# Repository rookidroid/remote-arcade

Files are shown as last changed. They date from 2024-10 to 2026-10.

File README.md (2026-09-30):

# Arcade Remote

A retro-style arcade controller for robots — a 4-way arcade joystick, five arcade buttons and an ESP32-C6, in a 3D-printed cabinet that fits in your hands.






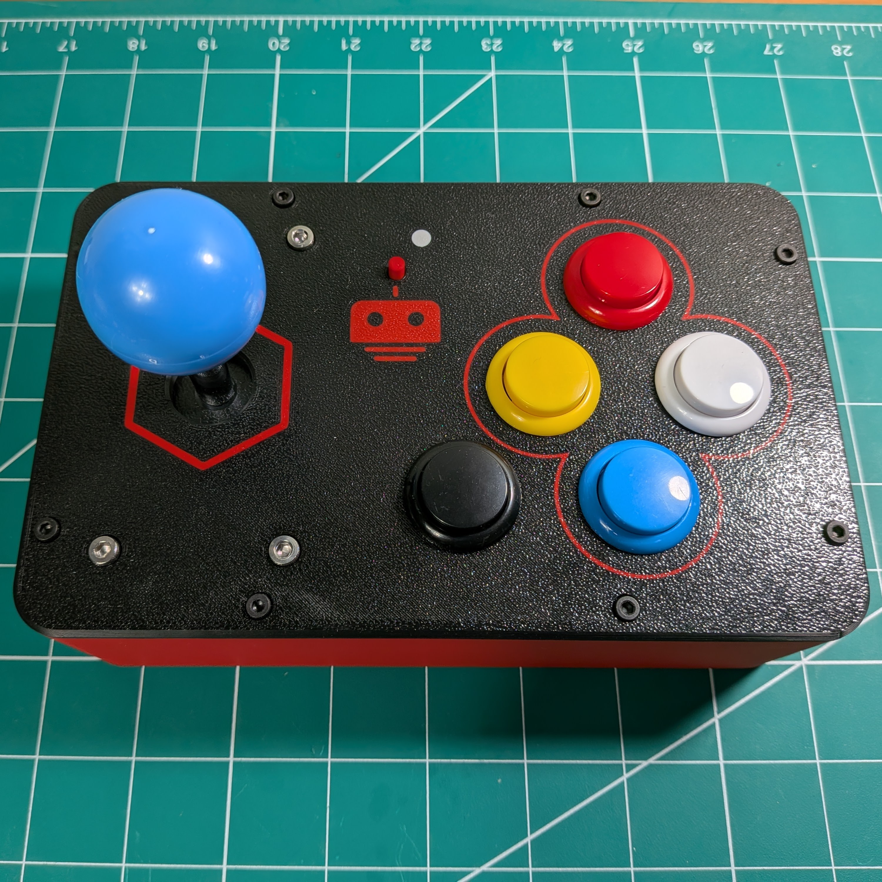
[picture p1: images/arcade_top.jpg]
arcade_top
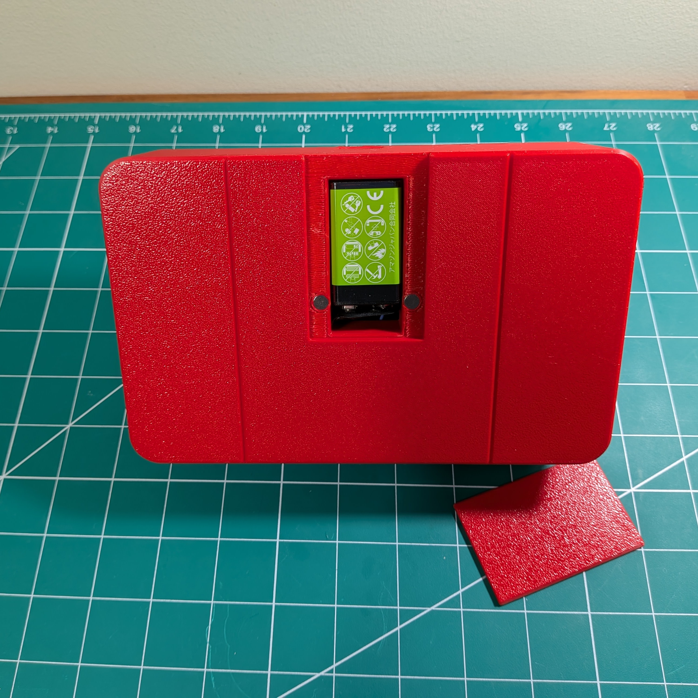
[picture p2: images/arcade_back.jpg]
arcade_back
 

**Jump to:** [Bill of Materials](#bill-of-materials) · [3D-Printed Parts](#3d-printed-parts) · [Assembly](#assembly) · [Firmware](#firmware) · [Controls](#controls) · [UDP Protocol](#udp-protocol) · [Troubleshooting](#troubleshooting)

<details>
<summary><b>Table of Contents</b></summary>

- [Introduction](#introduction)
  - [Specifications](#specifications)
- [Bill of Materials](#bill-of-materials)
  - [Electronics](#electronics)
  - [Connection Diagram](#connection-diagram)
  - [Pin Map](#pin-map)
  - [Other Parts](#other-parts)
- [3D-Printed Parts](#3d-printed-parts)
- [Assembly](#assembly)
- [Firmware](#firmware)
  - [Prerequisites](#prerequisites)
  - [Upload](#upload)
  - [Configuration](#configuration)
  - [Status LED](#status-led)
- [Controls](#controls)
- [UDP Protocol](#udp-protocol)
- [Troubleshooting](#troubleshooting)
- [Related Projects](#related-projects)
- [License](#license)
- [Support](#support)

</details>

## Introduction

This remote turns real arcade hardware into a WiFi controller for the [RookiDroid hexapod](https://github.com/rookidroid/hexapod) — **all three of them**, Nougat, Mochi and Macaroon — and any other robot that speaks the same binary UDP protocol. Only the `ssid` line in the sketch changes between robots; see [Configuration](#configuration).

Prefer a step-by-step walkthrough with photos? The same build is documented as the [Build the Arcade Remote](https://rookidroid.com/build-the-arcade-remote/) guide on rookidroid.com.

- **Real arcade feel** — a microswitch joystick and five snap-in arcade buttons, no analog sticks and no deadzone
- **All-digital inputs** — nine switches on `INPUT_PULLUP` GPIOs, scanned every 5 ms; a command must hold for 30 ms before it is sent, which filters switch bounce and half-pressed button combos
- **WiFi direct to the robot** — the remote joins the robot's own access point, so no router is involved, with WiFi power saving off for low latency
- **Instant send + 20 Hz heartbeat** — a new command goes out as soon as it settles, and the current one is repeated every 50 ms, so releasing a control stops the robot right away
- **Adjustable speed** — five speed levels from 20 % to 100 % of the robot's gait speed, stepped with special + joystick and remembered across power cycles
- **RGB status LED** — shows the link state, what the remote is sending and the speed level, visible through the window in the top panel
- **Battery powered** — a single 9 V battery in a magnetically-latched bay in the back
- **Fully 3D-printed cabinet** — one Bambu Studio project prints the whole enclosure

### Specifications

| Item | Value |
| ---- | ----- |
| **Controller** | ESP32-C6 SuperMini on the RookiDroid remote carrier board |
| **Inputs** | 4-way microswitch joystick + 5 arcade push buttons |
| **Feedback** | 1 × WS2812 (NeoPixel) RGB status LED on `GP8` |
| **Power** | 9 V battery → on-board Mini360 buck converter → 5 V, with a slide switch on the board |
| **Connectivity** | 2.4 GHz WiFi — the remote joins the robot's access point as a station |
| **Control** | 7-byte binary UDP packets to `192.168.4.1:1234`, carrying the command and the speed level |
| **Update rate** | Sent on change (30 ms settle), plus a 20 Hz heartbeat that runs continuously, including standby |
| **Enclosure** | 3D-printed body, cover, bottom plate and magnetic battery cover |

## Bill of Materials

### Electronics

| Name | Thumbnail | Required # | Specifications | Note |
| ---- | --- | --- | --- | ---- |
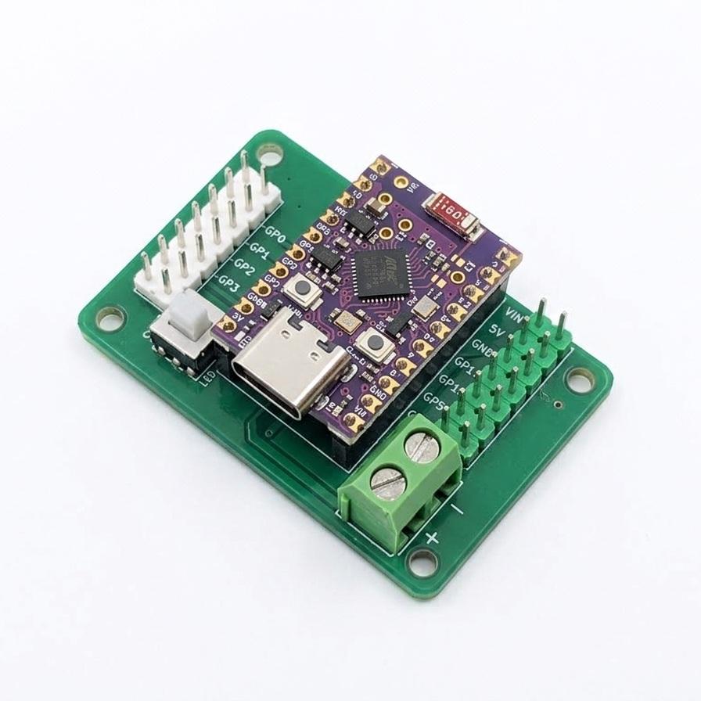
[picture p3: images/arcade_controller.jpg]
controller_board
| Controller board |  | 1 | ESP32-C6 SuperMini on a carrier board with a Mini360 buck converter, power switch, 2-pin battery terminal, a 5-pin joystick header (`GP0`–`GP3`) and a 2×7 button header | [Purchase](https://rookidroid.com/product/arcade-controller-board/) — or use a bare ESP32-C6 SuperMini, wiring the switches straight to the GPIOs in the [pin map](#pin-map) and feeding it 5 V |
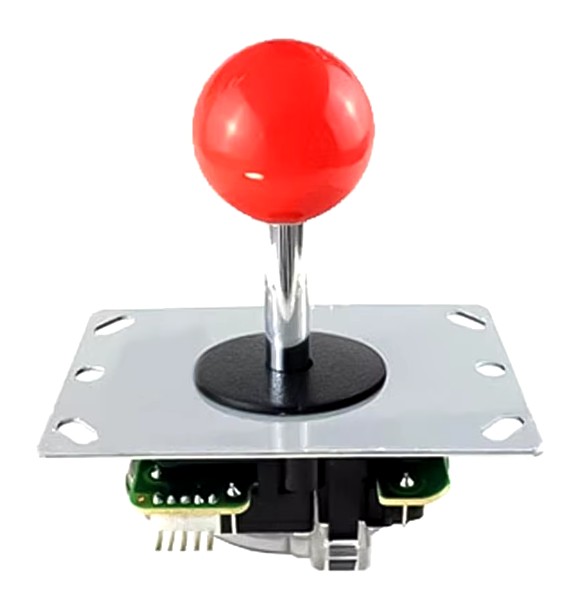
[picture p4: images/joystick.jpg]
joystick
| Arcade joystick |  | 1 | Microswitch joystick, 97 × 65 mm mounting plate, ~119 mm overall height, 5-pin harness | Ball top; the harness plugs into the joystick header |
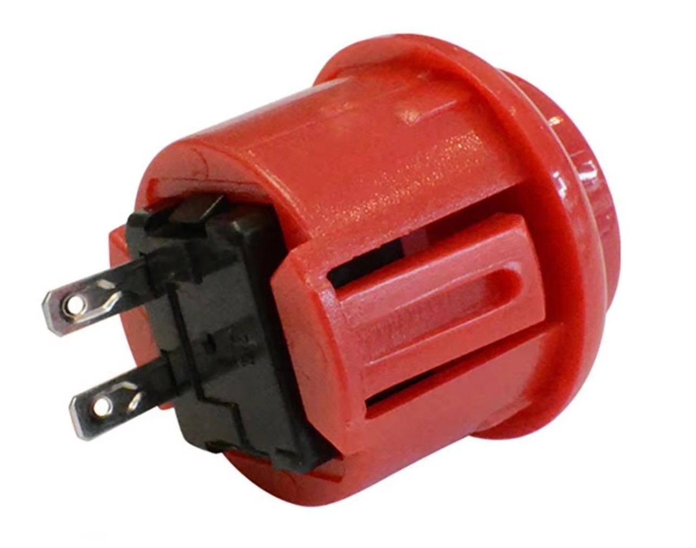
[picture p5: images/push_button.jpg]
push_button
| Arcade push button |  | 5 | 30 mm snap-in button with a microswitch (2 terminals) | Any five colors — four for the direction cluster, one for the special/modifier button |
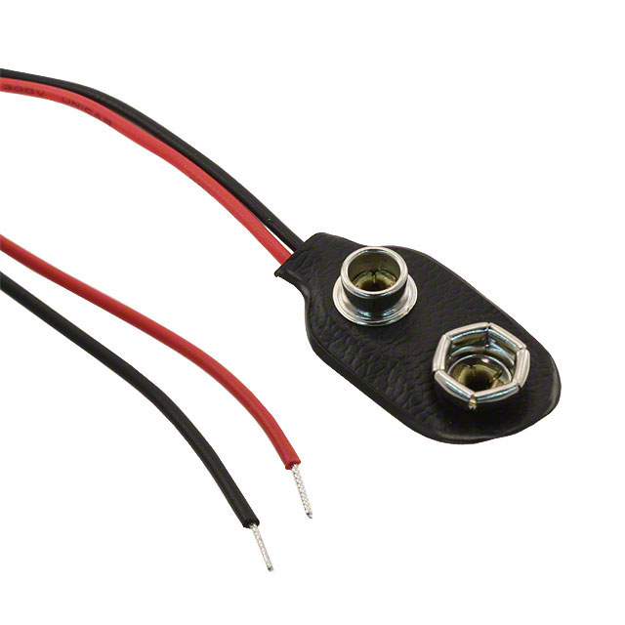
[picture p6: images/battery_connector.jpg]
battery_connector
| 9 V battery connector |  | 1 | Snap connector with flying leads | Screws into the 2-pin terminal block — mind the polarity |
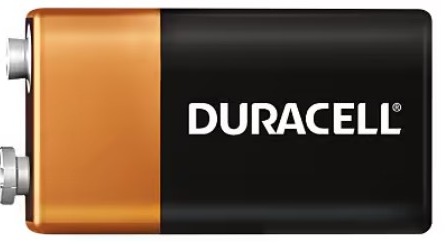
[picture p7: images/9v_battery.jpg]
9v_battery
| 9 V battery |  | 1 | Alkaline or rechargeable | Sits in the bay behind the magnetic cover |
| Jumper wires | — | ~11 | 2.8 mm spade or Dupont, 150–200 mm | One per button terminal; the joystick comes with its own harness |

### Connection Diagram

diagram

Every input is a plain switch to ground: the firmware enables the internal pull-ups, so one terminal goes to its signal pin and the other to any `GND` pin.

### Pin Map

| Input | Signal | GPIO | Where it lands on the board |
| ----- | --- | ---- | --- |
| Joystick up | `JS_UP` | `GP3` | 5-pin joystick header |
| Joystick down | `JS_DOWN` | `GP2` | 5-pin joystick header |
| Joystick left | `JS_LEFT` | `GP0` | 5-pin joystick header |
| Joystick right | `JS_RIGHT` | `GP1` | 5-pin joystick header |
| Button — up | `BT_UP` | `GP14` | 2×7 button header |
| Button — down | `BT_DOWN` | `GP15` | 2×7 button header |
| Button — left | `BT_LEFT` | `GP18` | 2×7 button header |
| Button — right | `BT_RIGHT` | `GP19` | 2×7 button header |
| Button — special | `BT_SPECIAL` | `GP20` | 2×7 button header |
| Status LED | `PIN_RGB` | `GP8` | On-board WS2812 of the SuperMini |

The four direction buttons are the cluster outlined on the top panel; the button sitting on its own is the special (modifier) button.

### Other Parts

| Name | Spec | Required # | Installation |
| ---- | ---- | --- | --- |
| Screw | M3 10 mm | 8 | Cover to body |
| Nut | M3 | 8 | Cover to body |
| Screw | M4 10 mm | 4 | Joystick mounting plate |
| Nut | M4 | 4 | Joystick mounting plate |
| Screw | M2 4 mm | 4 | Controller board to body |
| Magnet | 6 mm dia. × 2 mm | 4 | Hold the battery cover |

## 3D-Printed Parts

The whole cabinet is one Bambu Studio project: [`3d model/arcade.3mf`](./3d%20model/arcade.3mf), also a [free download](https://rookidroid.com/product/arcade-controller/) from the RookiDroid shop. The Fusion 360 source is [`3d model/arcade.f3d`](./3d%20model/arcade.f3d).

| Part | Required # | Note |
| ---- | --- | ---- |
| arcade body | 1 | Holds the controller board and the battery bay |
| arcade cover | 1 | Top panel with the joystick, button and LED cut-outs; multi-material, so the logo and outlines print in a second color |
| bottom | 1 | Closes the underside |
| battery cover | 1 | Magnetic latch, no screws |

**Print settings** (as saved in the project):

- Printer profile: Bambu Lab H2S, 0.4 mm nozzle
- Layer height: 0.2 mm
- Material: PLA
- Multi-color: the cover uses extra filaments for the logo and the button outlines — print it in a single color if you don't have an AMS

## Assembly

1. **Print the parts** and clean up the cut-outs — the buttons and the joystick shaft need a snug snap fit.
2. **Mount the inputs in the cover.** Snap the five buttons in, then bolt the joystick plate down with the M4 hardware.

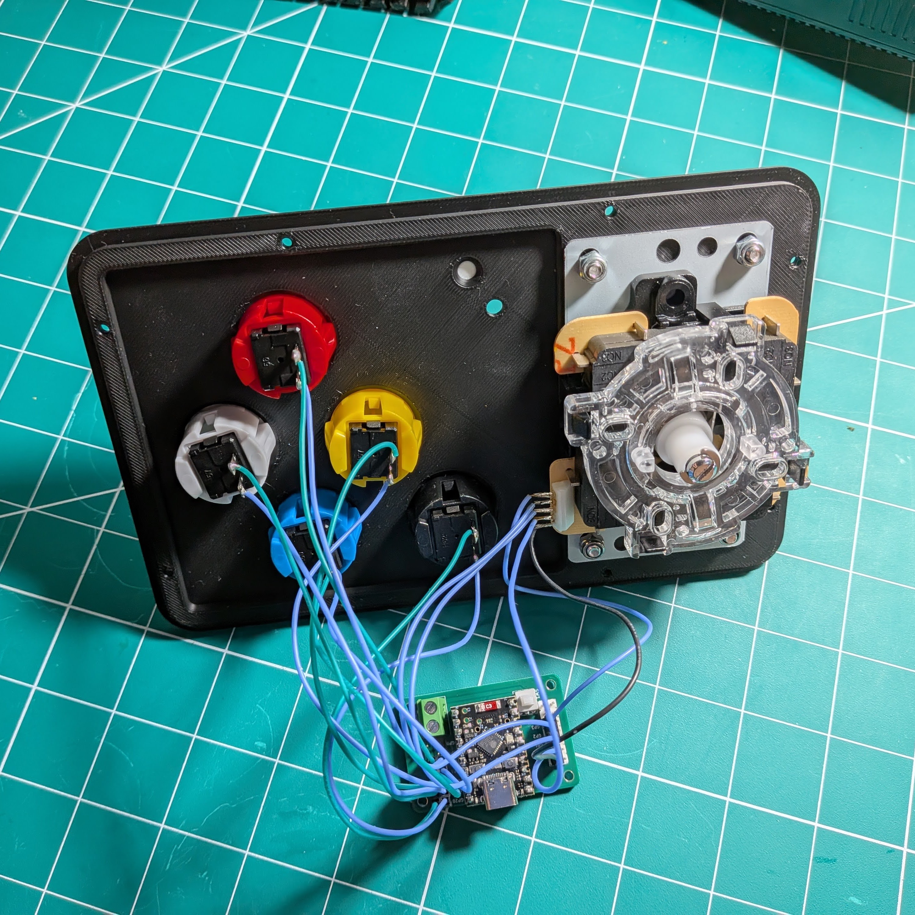
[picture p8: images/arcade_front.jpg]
arcade_front
   

3. **Mount the controller board** in the body on the M2 standoffs, with the USB-C port reachable for flashing.
4. **Wire it up.** Plug the joystick harness into the 5-pin header, then run one wire from each button to its GPIO on the 2×7 header and one to a `GND` pin — see the [connection diagram](#connection-diagram).
5. **Battery.** Screw the 9 V connector leads into the terminal block, minding polarity, and press the four magnets into the battery bay and its cover.
6. **Close it up** with the M3 screws and nuts, flash the [firmware](#firmware), and power it on.

## Firmware

The sketch lives in [`software/arcade/arcade.ino`](./software/arcade/arcade.ino).

### Prerequisites

- [Arduino IDE](https://www.arduino.cc/en/software) 2.x
- **esp32** board package 3.x or newer (Espressif Systems) — required for ESP32-C6 support
- **Adafruit NeoPixel** library

### Upload

1. Open `software/arcade/arcade.ino`.
2. Select **ESP32C6 Dev Module** as the board, and the port that appears when you plug in the USB-C cable.
3. Upload. If the port never enumerates, hold **BOOT**, tap **RESET**, release **BOOT**, and try again.
4. Open the Serial Monitor at **115200 baud** to watch the WiFi connection.

### Configuration

Edit these near the top of the sketch to match your robot:

| Setting | Default | Meaning |
| --- | --- | --- |
| `ssid` | `hexapod_nougat` | The access point the robot hosts |
| `password` | `hexapod_1234` | Its passphrase |
| `udpAddress` | `192.168.4.1` | The robot's IP as the AP |
| `udpPort` | `1234` | UDP port the robot listens on |

The remote connects in the background and keeps retrying, so the robot and the remote can be powered up in either order. If the robot drops out, the remote reconnects on its own when it comes back.

The same remote drives every RookiDroid hexapod — each one hosts its own access point at `192.168.4.1` and listens on port `1234`, so only `ssid` changes:

| Robot | `ssid` | `password` | Build guide |
| ----- | --- | --- | --- |
| Hexapod Nougat | `hexapod_nougat` | `hexapod_1234` | [Build Nougat](https://rookidroid.com/build-your-own-nougat/) |
| Hexapod Mochi | `hexapod` | `hexapod_1234` | [Build Mochi](https://rookidroid.com/build-your-own-mochi/) |
| Hexapod Macaroon | `hexapod_macaroon` | `hexapod_1234` | [Build Macaroon](https://rookidroid.com/build-your-own-macaroon/) |

If you changed the credentials in your robot's own `config.h`, match them here.

### Status LED

| Color | Meaning |
| ----- | --- |
| Off | No power |
| Blinking blue | Connecting to the robot for the first time |
| Blinking red | WiFi lost; the remote keeps retrying and recovers when the robot comes back |
| Green | Connected, standing by |
| Cyan | Connected, walking or turning |
| Yellow | Connected, turbo (fast forward/backward) |
| Magenta | Connected, body motion (pitch, roll, yaw or twist) |
| White flash | Speed level changed |

While connected, the LED **brightness** shows the speed level: dimmest at 20 %, brightest at 100 %.

## Controls

The firmware reads all nine switches every 5 ms and maps them to exactly one command. Once a new command has held for 30 ms, it is sent right away. The current command is also resent every 50 ms as a heartbeat. Nothing pressed sends `CMD_STANDBY`, so the robot stops as soon as you let go.

The 30 ms settle time means you don't have to press combos such as **special + up** perfectly together: the command the robot gets is the finished combo, not whichever button closed first.

**Joystick** (takes priority over the direction buttons; special + joystick changes the speed instead, see below):

| Joystick | Command | Action |
| --- | --- | --- |
| Up | `CMD_WALK_0` | Walk forward |
| Down | `CMD_WALK_180` | Walk backward |
| Left | `CMD_WALK_L90` | Sidestep left |
| Right | `CMD_WALK_R90` | Sidestep right |
| Up + Left | `CMD_WALK_L45` | Walk forward-left |
| Up + Right | `CMD_WALK_R45` | Walk forward-right |
| Down + Left | `CMD_WALK_L135` | Walk backward-left |
| Down + Right | `CMD_WALK_R135` | Walk backward-right |

**Buttons** (when the joystick is centered):

| Button | Command | Action |
| --- | --- | --- |
| Up | `CMD_WALK_0` | Walk forward |
| Down | `CMD_WALK_180` | Walk backward |
| Left | `CMD_TURN_LEFT` | Turn left in place |
| Right | `CMD_TURN_RIGHT` | Turn right in place |
| Special + Up | `CMD_ROTATE_X` | Body pitch |
| Special + Left | `CMD_ROTATE_Y` | Body roll |
| Special + Right | `CMD_ROTATE_Z` | Body yaw |
| Special + Down | `CMD_TWIST` | Body twist |

**Turbo:** hold the **up** button while pushing the joystick up for `CMD_FAST_FORWARD`, or the **down** button while pulling the joystick down for `CMD_FAST_BACKWARD`.

**Speed:** hold **special** and flick the joystick **up** to speed up one level, or **down** to slow down one level. The robot holds still while special and the joystick are both pressed. There are five levels — 20, 40, 60, 80 and 100 % of the robot's gait speed — starting at 60 %. Each flick steps one level (holding does not repeat), the LED flashes white, and its brightness then shows the new level. The level is saved in the remote's flash and restored at power-on, and it is sent with every packet, so the robot always follows the remote.

## UDP Protocol

Each packet is 7 bytes, little-endian and unpadded, sent to `192.168.4.1:1234`:

| Offset | Field | Type | Value |
| --- | ----- | ---- | ----- |
| 0 | `magic` | `uint8` | `0xA5` — motion command |
| 1 | `cmd` | `uint8` | Command ID from the table below |
| 2–5 | `seq_num` | `uint32` | Increments on every packet |
| 6 | `speed_pct` | `uint8` | Gait speed in percent: 20, 40, 60, 80 or 100 |

> **Robot firmware:** the speed byte needs hexapod firmware with motion-speed support. Older firmware only accepts the 6-byte packet and ignores this remote — update the robot too.

| ID | Command | Sent by this remote |
| -- | --- | --- |
| 0 | `CMD_STANDBY` | Yes — nothing pressed |
| 1 | `CMD_WALK_0` | Yes |
| 2 | `CMD_WALK_180` | Yes |
| 3 | `CMD_WALK_R45` | Yes |
| 4 | `CMD_WALK_R90` | Yes |
| 5 | `CMD_WALK_R135` | Yes |
| 6 | `CMD_WALK_L45` | Yes |
| 7 | `CMD_WALK_L90` | Yes |
| 8 | `CMD_WALK_L135` | Yes |
| 9 | `CMD_FAST_FORWARD` | Yes — turbo |
| 10 | `CMD_FAST_BACKWARD` | Yes — turbo |
| 11 | `CMD_TURN_LEFT` | Yes |
| 12 | `CMD_TURN_RIGHT` | Yes |
| 13 | `CMD_CLIMB_FORWARD` | Not mapped to a control |
| 14 | `CMD_CLIMB_BACKWARD` | Not mapped to a control |
| 15 | `CMD_ROTATE_X` | Yes — special + up |
| 16 | `CMD_ROTATE_Y` | Yes — special + left |
| 17 | `CMD_ROTATE_Z` | Yes — special + right |
| 18 | `CMD_TWIST` | Yes — special + down |

The layout matches `UdpControlPacket` in the hexapod firmware — see the [hexapod UDP reference](https://github.com/rookidroid/hexapod#sending-udp-commands) for the other packet types the robot understands.

## Troubleshooting

| Symptom | Things to check |
| --- | --- |
| LED keeps blinking blue | The robot isn't powered up, or the SSID/password don't match — the remote keeps retrying until it finds the AP |
| LED is green but the robot ignores the remote | `udpAddress` and `udpPort` must match the robot, the robot must be in its normal (non-calibration) mode, and its firmware must accept the 7-byte packet — see [UDP Protocol](#udp-protocol) |
| Robot walks slowly | The speed level is low — hold special and flick the joystick up; a dim LED means a low level |
| One direction never triggers | Check that switch's signal wire and its `GND` — an unconnected `INPUT_PULLUP` pin just reads high forever |
| Diagonals don't work | The joystick has a 4-way restrictor plate fitted; swap in the 8-way gate |
| Robot keeps moving after you let go | Standby packets aren't arriving — check the WiFi link; the robot should also have its own failsafe |
| Board doesn't enumerate over USB | Hold **BOOT**, tap **RESET**, release **BOOT**, then upload |

## Related Projects

| Project | What it is |
| --- | --- |
| [Build the Arcade Remote](https://rookidroid.com/build-the-arcade-remote/) | The four-phase build guide for this remote, with photos and wiring |
| [hexapod](https://github.com/rookidroid/hexapod) | The robot this remote drives — Nougat, Mochi and Macaroon all share the UDP protocol |
| [Arcade Controller](https://rookidroid.com/product/arcade-controller/) | The 3D print files for this cabinet, as a free download |
| [Arcade Controller Board](https://rookidroid.com/product/arcade-controller-board/) | The ESP32-C6 carrier board used here |
| [hexapod-link](https://github.com/rookidroid/hexapod-link) | Desktop app for real-time pose streaming to the hexapod |

## License

This project is licensed under the **MIT License** — see [LICENSE](./LICENSE) for the full text.

## Support

- Website: [rookidroid.com](https://rookidroid.com/)
- Build guide: [Build the Arcade Remote](https://rookidroid.com/build-the-arcade-remote/)
- Email: [info@rookidroid.com](mailto:info@rookidroid.com)
- Bugs and build questions: [GitHub Issues](https://github.com/rookidroid/remote-arcade/issues)

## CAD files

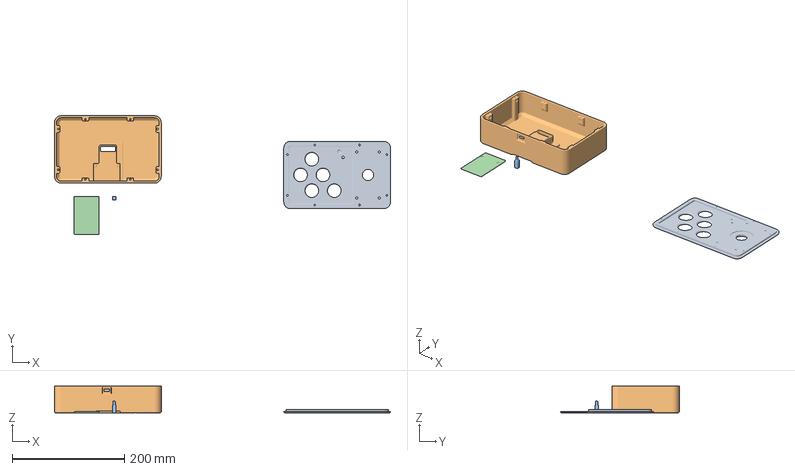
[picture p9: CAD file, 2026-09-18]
3d model/arcade.3mf
598.0 x 211.0 x 48.0 mm
arcade body.stl
buttom.stl
battery_cover (1).stl

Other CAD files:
3d model/arcade.f3d

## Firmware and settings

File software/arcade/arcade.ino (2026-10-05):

/*
 *
 *    This sketch is for the WiFi joystick
 *
 *    ----------
 *    Copyright (C) 2022 - PRESENT  Zhengyu Peng
 *    Website: https://zpeng.me
 *
 *    `                      `
 *    -:.                  -#:
 *    -//:.              -###:
 *    -////:.          -#####:
 *    -/:.://:.      -###++##:
 *    ..   `://:-  -###+. :##:
 *           `:/+####+.   :##:
 *    .::::::::/+###.     :##:
 *    .////-----+##:    `:###:
 *     `-//:.   :##:  `:###/.
 *       `-//:. :##:`:###/.
 *         `-//:+######/.
 *           `-/+####/.
 *             `+##+.
 *              :##:
 *              :##:
 *              :##:
 *              :##:
 *              :##:
 *               .+:
 *
 */

#include <Preferences.h>
#include <WiFi.h>
#include <WiFiUdp.h>

#include <Adafruit_NeoPixel.h>

// GPIO pin number for the LED
#define PIN_RGB 8

// GPIO pin number for the joystick
#define JS_UP 3
#define JS_DOWN 2
#define JS_LEFT 0
#define JS_RIGHT 1

// GPIO pin number for the buttons
#define BT_UP 14
#define BT_DOWN 15
#define BT_LEFT 18
#define BT_RIGHT 19
#define BT_SPECIAL 20


// WiFi parameters
const char *ssid = "hexapod_macaroon";
const char *password = "hexapod_1234";

// UDP
WiFiUDP udp;
const IPAddress udpAddress(192, 168, 4, 1);
const int udpPort = 1234;

// Timing (ms)
const unsigned long SCAN_PERIOD_MS = 5;    // How often the switches are read
const unsigned long SETTLE_MS = 30;        // A new command must hold this long before it is sent
const unsigned long HEARTBEAT_MS = 50;     // Resend the current command at 20 Hz
const unsigned long RECONNECT_MS = 10000;  // Kick the WiFi stack if the link stays down this long
const unsigned long BLINK_MS = 250;        // Half period of the status LED blink
const unsigned long SPEED_FLASH_MS = 150;  // White flash when the speed level changes

// Status LED brightness (0-255); full brightness is blinding through the window
const uint8_t LED_BRIGHTNESS = 40;

// Motion speed levels, in percent of the robot's tuned gait speed. Special +
// joystick up/down steps through them; the LED brightness shows the level.
const uint8_t SPEED_LEVELS[] = { 20, 40, 60, 80, 100 };
const uint8_t LED_LEVEL_BRIGHTNESS[] = { 8, 16, 24, 32, LED_BRIGHTNESS };
const int SPEED_LEVEL_COUNT = sizeof(SPEED_LEVELS) / sizeof(SPEED_LEVELS[0]);
const int DEFAULT_SPEED_LEVEL = 2;  // 60%

static_assert(sizeof(LED_LEVEL_BRIGHTNESS) == sizeof(SPEED_LEVELS),
              "one LED brightness per speed level");

// The speed level survives power cycles in NVS
Preferences prefs;
const char *PREFS_NAMESPACE = "arcade";
const char *PREFS_SPEED_KEY = "speed";

Adafruit_NeoPixel rgbLed(1, PIN_RGB, NEO_GRB + NEO_KHZ800);

enum RobotCommand : uint8_t {
  CMD_STANDBY = 0,
  CMD_WALK_0 = 1,
  CMD_WALK_180 = 2,
  CMD_WALK_R45 = 3,
  CMD_WALK_R90 = 4,
  CMD_WALK_R135 = 5,
  CMD_WALK_L45 = 6,
  CMD_WALK_L90 = 7,
  CMD_WALK_L135 = 8,
  CMD_FAST_FORWARD = 9,
  CMD_FAST_BACKWARD = 10,
  CMD_TURN_LEFT = 11,
  CMD_TURN_RIGHT = 12,
  CMD_CLIMB_FORWARD = 13,
  CMD_CLIMB_BACKWARD = 14,
  CMD_ROTATE_X = 15,
  CMD_ROTATE_Y = 16,
  CMD_ROTATE_Z = 17,
  CMD_TWIST = 18
};

#pragma pack(push, 1)
struct UdpControlPacket {
  uint8_t magic;      // 0xA5
  RobotCommand cmd;
  uint32_t seq_num;
  uint8_t speed_pct;  // Gait playback speed in percent
};
#pragma pack(pop)

uint32_t packet_seq_num = 0;

// Command state
RobotCommand candidate_cmd = CMD_STANDBY;  // Latest reading, still settling
RobotCommand active_cmd = CMD_STANDBY;     // Command being sent to the robot
unsigned long candidate_since_ms = 0;
unsigned long last_scan_ms = 0;
unsigned long last_send_ms = 0;

// Speed gesture state (special + joystick up/down), settled like commands
int candidate_gesture = 0;  // Latest reading: +1 faster, -1 slower, 0 none
int active_gesture = 0;     // Settled gesture
unsigned long gesture_since_ms = 0;

int speed_level = DEFAULT_SPEED_LEVEL;
unsigned long speed_flash_until_ms = 0;

// Link state, polled from loop() so nothing is shared with the WiFi task
bool link_up = false;
bool ever_connected = false;
unsigned long last_reconnect_ms = 0;


struct RGB {
  uint8_t r, g, b;
};

constexpr RGB COLOR_OFF = { 0, 0, 0 };
constexpr RGB COLOR_RED = { 255, 0, 0 };
constexpr RGB COLOR_GREEN = { 0, 255, 0 };
constexpr RGB COLOR_BLUE = { 0, 0, 255 };
constexpr RGB COLOR_CYAN = { 0, 255, 255 };
constexpr RGB COLOR_YELLOW = { 255, 180, 0 };
constexpr RGB COLOR_MAGENTA = { 255, 0, 255 };
constexpr RGB COLOR_WHITE = { 255, 255, 255 };

RGB led_color = COLOR_OFF;
uint8_t led_brightness = LED_BRIGHTNESS;

void setColor(const RGB &color, uint8_t brightness) {
  // Only touch the LED when something changes; show() is not free
  if (color.r == led_color.r && color.g == led_color.g && color.b == led_color.b
      && brightness == led_brightness) {
    return;
  }
  led_color = color;
  led_brightness = brightness;
  // setBrightness() scales the stored pixel lossily, so set the color after it
  rgbLed.setBrightness(brightness);
  rgbLed.setPixelColor(0, rgbLed.Color(color.r, color.g, color.b));
  rgbLed.show();
}

void setup() {
  // initilize hardware serial:
  Serial.begin(115200);
  delay(10);

  rgbLed.begin();
  rgbLed.setBrightness(LED_BRIGHTNESS);
  rgbLed.show();

  pinMode(JS_UP, INPUT_PULLUP);
  pinMode(JS_DOWN, INPUT_PULLUP);
  pinMode(JS_LEFT, INPUT_PULLUP);
  pinMode(JS_RIGHT, INPUT_PULLUP);
  pinMode(BT_UP, INPUT_PULLUP);
  pinMode(BT_DOWN, INPUT_PULLUP);
  pinMode(BT_LEFT, INPUT_PULLUP);
  pinMode(BT_RIGHT, INPUT_PULLUP);
  pinMode(BT_SPECIAL, INPUT_PULLUP);

  prefs.begin(PREFS_NAMESPACE, false);
  speed_level = prefs.getUChar(PREFS_SPEED_KEY, DEFAULT_SPEED_LEVEL);
  if (speed_level >= SPEED_LEVEL_COUNT) {
    speed_level = DEFAULT_SPEED_LEVEL;
  }
  Serial.print("Speed: ");
  Serial.print(SPEED_LEVELS[speed_level]);
  Serial.println("%");

  // Connect in the background; loop() tracks the link and keeps retrying
  WiFi.mode(WIFI_STA);
  // Modem sleep holds packets for up to a beacon interval; the remote needs low latency
  WiFi.setSleep(false);
  WiFi.setAutoReconnect(true);
  WiFi.begin(ssid, password);
  last_reconnect_ms = millis();

  Serial.print("Connecting to ");
  Serial.println(ssid);
}


void loop() {
  const unsigned long now = millis();

  updateLink(now);

  if (now - last_scan_ms >= SCAN_PERIOD_MS) {
    last_scan_ms = now;
    scanInputs(now);
  }

  if (now - last_send_ms >= HEARTBEAT_MS) {
    sendCommand(active_cmd, now);
  }

  updateLed(now);

  delay(1);  // Yield to the WiFi task
}

/**
   Read the switches and return the command they select. The joystick takes
   priority over the buttons.
*/
RobotCommand readCommand() {
  // Switches pull to ground when pressed
  const bool js_up = digitalRead(JS_UP) == LOW;
  const bool js_down = digitalRead(JS_DOWN) == LOW;
  const bool js_left = digitalRead(JS_LEFT) == LOW;
  const bool js_right = digitalRead(JS_RIGHT) == LOW;

  const bool bt_up = digitalRead(BT_UP) == LOW;
  const bool bt_down = digitalRead(BT_DOWN) == LOW;
  const bool bt_left = digitalRead(BT_LEFT) == LOW;
  const bool bt_right = digitalRead(BT_RIGHT) == LOW;
  const bool bt_special = digitalRead(BT_SPECIAL) == LOW;

  const int js_count = js_up + js_down + js_left + js_right;

  // Special + joystick adjusts the speed; hold still meanwhile
  if (bt_special && js_count > 0) {
    return CMD_STANDBY;
  }

  if (js_count == 2) {
    // Diagonals
    if (js_up && js_left) return CMD_WALK_L45;
    if (js_up && js_right) return CMD_WALK_R45;
    if (js_down && js_left) return CMD_WALK_L135;
    if (js_down && js_right) return CMD_WALK_R135;
    return CMD_STANDBY;
  }

  if (js_count > 0) {
    // Holding the matching button turns a straight walk into turbo
    if (js_up) return bt_up ? CMD_FAST_FORWARD : CMD_WALK_0;
    if (js_down) return bt_down ? CMD_FAST_BACKWARD : CMD_WALK_180;
    if (js_left) return CMD_WALK_L90;
    if (js_right) return CMD_WALK_R90;
    return CMD_STANDBY;
  }

  if (bt_special) {
    if (bt_up) return CMD_ROTATE_X;
    if (bt_left) return CMD_ROTATE_Y;
    if (bt_right) return CMD_ROTATE_Z;
    if (bt_down) return CMD_TWIST;
    return CMD_STANDBY;
  }

  if (bt_up) return CMD_WALK_0;
  if (bt_down) return CMD_WALK_180;
  if (bt_left) return CMD_TURN_LEFT;
  if (bt_right) return CMD_TURN_RIGHT;

  return CMD_STANDBY;
}

/**
   Read the speed gesture: +1 for special + joystick up, -1 for special +
   joystick down, 0 otherwise.
*/
int readSpeedGesture() {
  if (digitalRead(BT_SPECIAL) != LOW) {
    return 0;
  }

  const bool js_up = digitalRead(JS_UP) == LOW;
  const bool js_down = digitalRead(JS_DOWN) == LOW;
  const bool js_left = digitalRead(JS_LEFT) == LOW;
  const bool js_right = digitalRead(JS_RIGHT) == LOW;

  if (js_left || js_right) {
    return 0;
  }
  if (js_up && !js_down) return 1;
  if (js_down && !js_up) return -1;
  return 0;
}

/**
   Step the speed level once per settled gesture, remember it, and tell the
   robot right away.
*/
void scanSpeedGesture(unsigned long now) {
  const int reading = readSpeedGesture();

  if (reading != candidate_gesture) {
    candidate_gesture = reading;
    gesture_since_ms = now;
    return;
  }

  if (candidate_gesture == active_gesture || now - gesture_since_ms < SETTLE_MS) {
    return;
  }
  active_gesture = candidate_gesture;

  // Act on the flick only; holding the stick does not repeat
  if (active_gesture == 0) {
    return;
  }

  const int level = constrain(speed_level + active_gesture, 0, SPEED_LEVEL_COUNT - 1);
  if (level == speed_level) {
    return;
  }
  speed_level = level;
  prefs.putUChar(PREFS_SPEED_KEY, speed_level);
  speed_flash_until_ms = now + SPEED_FLASH_MS;

  Serial.print("Speed: ");
  Serial.print(SPEED_LEVELS[speed_level]);
  Serial.println("%");

  sendCommand(active_cmd, now);
}

/**
   Sample the inputs and switch to a new command once it has settled.

   Pressing a chord such as special + up rarely closes both switches in the
   same sample, and the robot commits to a whole gait cycle if a stray command
   lands on one of its switch points. Requiring SETTLE_MS of stability filters
   those transients (and switch bounce) out.
*/
void scanInputs(unsigned long now) {
  scanSpeedGesture(now);

  const RobotCommand reading = readCommand();

  if (reading != candidate_cmd) {
    candidate_cmd = reading;
    candidate_since_ms = now;
    return;
  }

  if (candidate_cmd != active_cmd && now - candidate_since_ms >= SETTLE_MS) {
    active_cmd = candidate_cmd;
    // Send right away instead of waiting for the next heartbeat
    sendCommand(active_cmd, now);
  }
}

/**
   Send one motion packet. The heartbeat timer restarts even while the link is
   down, so a dead link does not spin on send attempts.
*/
void sendCommand(RobotCommand cmd, unsigned long now) {
  last_send_ms = now;

  if (!link_up) {
    return;
  }

  UdpControlPacket packet;
  packet.magic = 0xA5;
  packet.cmd = cmd;
  packet.seq_num = packet_seq_num++;
  packet.speed_pct = SPEED_LEVELS[speed_level];

  udp.beginPacket(udpAddress, udpPort);
  udp.write((const uint8_t *)&packet, sizeof(packet));
  udp.endPacket();
}

/**
   Track the WiFi link and nudge the stack if it stays down.
*/
void updateLink(unsigned long now) {
  const bool up = WiFi.status() == WL_CONNECTED;

  if (up && !link_up) {
    link_up = true;
    ever_connected = true;
    Serial.print("WiFi connected! IP address: ");
    Serial.println(WiFi.localIP());
    udp.begin(udpPort);
    // Tell the robot what the controls say straight away
    sendCommand(active_cmd, now);
  } else if (!up && link_up) {
    link_up = false;
    last_reconnect_ms = now;
    Serial.println("WiFi lost connection");
    udp.stop();
  }

  // Auto-reconnect normally handles this; retry by hand if it gets stuck
  if (!link_up && now - last_reconnect_ms >= RECONNECT_MS) {
    last_reconnect_ms = now;
    Serial.println("Retrying WiFi connection");
    WiFi.reconnect();
  }
}

/**
   LED color for a command category.
*/
RGB commandColor(RobotCommand cmd) {
  switch (cmd) {
    case CMD_STANDBY:
      return COLOR_GREEN;
    case CMD_FAST_FORWARD:
    case CMD_FAST_BACKWARD:
      return COLOR_YELLOW;
    case CMD_ROTATE_X:
    case CMD_ROTATE_Y:
    case CMD_ROTATE_Z:
    case CMD_TWIST:
      return COLOR_MAGENTA;
    default:
      return COLOR_CYAN;
  }
}

/**
   Blink blue while connecting, red once the link is lost, and show the
   active command's category while connected, dimmed to the speed level.
*/
void updateLed(unsigned long now) {
  if (link_up) {
    // Signed difference, so the flash ends cleanly across millis() wraparound
    if ((long)(speed_flash_until_ms - now) > 0) {
      setColor(COLOR_WHITE, LED_BRIGHTNESS);
    } else {
      setColor(commandColor(active_cmd), LED_LEVEL_BRIGHTNESS[speed_level]);
    }
    return;
  }

  const bool blink_on = (now / BLINK_MS) % 2 == 0;
  if (!blink_on) {
    setColor(COLOR_OFF, LED_BRIGHTNESS);
  } else {
    setColor(ever_connected ? COLOR_RED : COLOR_BLUE, LED_BRIGHTNESS);
  }
}

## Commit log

2024-12-23 correct wiring mistake
2024-12-23 use interrupt for the buttons
2025-09-29 Update arcade body.3mf
    [arcade body.3mf]
2026-09-20 Revamp README: expanded docs & BOM
    Replace the minimal README with a full, user-friendly project guide. Adds badges, photos, table of contents, detailed Bill of Materials, connection diagram, pin map, 3D print details, assembly and firmware upload/configuration instructions, controls and UDP protocol reference, troubleshooting, license and support info. Clarifies ESP32-C6 usage, status LED behavior, and packet format for interoperability with the hexapod firmware.
2026-09-30 Improve arcade remote input and WiFi stability
    This commit refactors the arcade remote firmware to scan inputs every 5 ms, require a 30 ms settle window before sending a new command, and keep sending the active command as a 20 Hz heartbeat. It also moves WiFi setup to a background reconnect loop with automatic recovery, updates LED status behavior to reflect connection and command state, and refreshes the README to document the new behavior and control semantics.
    [arcade.ino]
2026-09-30 Add speed control to remote and protocol
    The remote now stores a persistent gait speed level, steps it with special+joystick gestures, and includes the selected value in every 7-byte UDP packet sent to the robot. The LED reflects the active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
2026-10-05 Update arcade icon and WiFi SSID
    This commit adds a new SVG cabinet icon for the remote arcade and updates the device WiFi SSID from hexapod_nougat to hexapod_macaroon. The change keeps the branding assets aligned with the current hardware and ensures the board connects to the correct network.
    [arcade.ino]

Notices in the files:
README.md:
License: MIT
